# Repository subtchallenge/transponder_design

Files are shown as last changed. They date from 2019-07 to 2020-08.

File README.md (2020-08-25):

# E-Stop Transmitter Design Files

*Version 2 - FEB 2020*

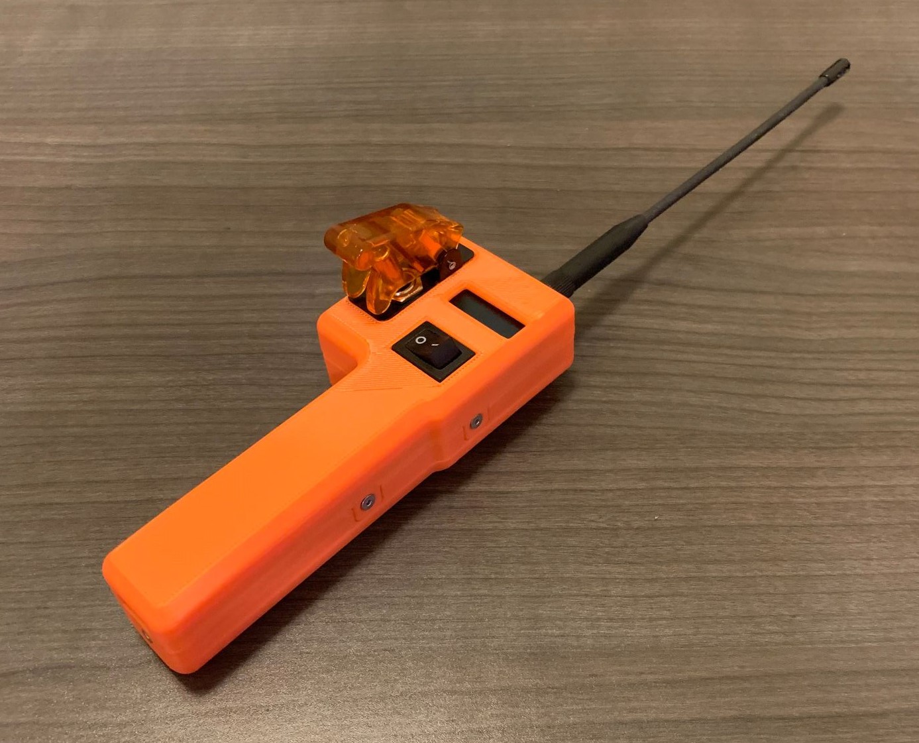
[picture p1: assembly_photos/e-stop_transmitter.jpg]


## Contents:
1. [3D Printing](#1-3d-printing)
2. [XBee Configuration](#2-xbee-configuration)
3. [Assembly](#3-assembly)
4. [Programming](#4-programming)
5. [Operation](#5-operation)

## 1. 3D Printing

The case of the E-Stop transmitter is comprised of two parts: an upper receiver and a lower receiver.  Each receiver houses several components, and the two parts mate together to form the body of the transmitter.

The design files for these parts have been provided in this package:

```
./hardware/lower_receiver.stp
./hardware/upper_receiver.stp
```

These parts are intended to be 3D printed.  The original design allows for printing on a standard desktop FDM 3D printer with a single extruder.  Other printers may be used at your own discretion.

It is recommended that the parts be printed in ABS plastic, however PLA or another form of plastic may be used as well.

For printing on a single-extruder printer without dissolvable filament, both receivers must be printed with the interior (hollow) face mated to the bed of the printer.  Supports must be used.  We recommend using Simplify 3D as a slicer because it has superior support structure generation.

Curling may be an issue for ABS prints due to the low surface area mating the part to the bed.  A raft is recommended for all plastics.  For ABS, a heated build plate and enclosed print volume will be necessary.

After printing, ensure that all dissolvable or supporting material is fully removed, or certain components will not fit (especially the rechargeable battery).

## 2. XBee Configuration

Before assembling your transmitter, you must configure the transmitter's XBee module.  This can be accomplished using Digi's XCTU utility and the XBee configuration file provided in this package.

1. Download and install the XCTU utility from the [Digi website](https://www.digi.com/products/iot-platform/xctu#productsupport-utilities).
2. Connect the XBee to the computer using the USB Adapter Board from your transponder.
3. Click the **Add Radio** button in XCTU to connect to the XBee. Once connected, make sure that your working mode in XCTU is set to _Configuration Mode_.
4. Click the **Profile** button, followed by **Apply Configuration**. This will bring up a dialog to select a configuration profile to upload to your XBee.
5. Select the profile provided in this package at `./xbee_profiles/e-stop_configuration.xpro`. This will start uploading the configuration to your XBee.
6. Set your **Node Identifier (NI)** parameter to match the following format: `my_transmitter_name-my_team_name`. For example, you may use `ES1-DARPA` (where ES1 stands for E-Stop #1, and the team name is DARPA).
    * **NOTE:** Do not use a dash ('-') in any part of the transmitter OR team name. This is a reserved character.
	* **NOTE:** `my_transmitter_name` must be 3 characters or less.
	* **NOTE:** `my_team_name` must be 11 characters or less.
    * **NOTE:** Don't forget to click the **Write** button to save the parameter to your Xbee.
7. You may optionally set a common encryption key for your transmitter and transponder XBees using the **AES Encryption Key (KY)** parameter.

Your e-stop transmitter is now properly configured.

**NOTE:** You may use the same process above to configure your platform transponders.  In step 5, simply load the transponder's configuration instead, which is provided in this package at `./xbee_profiles/transponder_configuration.xpro`.

## 3. Assembly

This section provides all information needed to assemble the E-Stop Transmitter.

**Supporting Files:**

* Electrical Schematic: `./electrical_schematic.jpg`
* Assembly Photos: `./assembly_photos/*`

**Tools Needed:**

* Soldering Iron
* Solder
* Wire Cutter/Stripper
* Exacto Blade
* M2, M2.5, and M3 taps
* 2mm and 2.5mm Hex Drivers
* Hot Glue Gun or Super Glue
* Multimeter
* Crescent Wrench

**Instructions:**

_NOTE: Most steps have supporting images in the assembly_photos directory._

1. Use the metric taps to thread the upper and lower receivers.
    * Use the M2.5 tap on the case mating holes on the sides of the lower receiver.
	* Use the M2 tap for the OLED mounting holes on the lower receiver.
	* Use the M3 tap for the XBee carrier mounting holes on the upper receiver.
2. Insert the battery into the lower receiver, with the wires facing towards the top of the receiver. [(photo)](assembly_photos/step_2.jpg)
3. Attach the _E-Stop Toggle Switch_ to the upper receiver using the following steps:
	* Bend the two bottom pins of the _E-Stop Toggle Switch_ to a 90deg angle. [(photo)](assembly_photos/step_3a.jpg)
    * Adjust the vertical positioning nut on the bore of the switch so that there is just enough thread on the outside of the upper receiver to place the cover and outer nut. [(photo)](assembly_photos/step_3a.jpg)
	* Insert the switch in through the back of the upper receiver, with the side with two pins facing towards the bottom of the upper receiver. [(photo)](assembly_photos/step_3a.jpg)
	* Place the toggle cover (in the open position) on the outside of the upper receiver, and fasten tightly using the second nut. [(photo)](assembly_photos/step_3b.jpg)
4. Attach the _Power Rocker Switch_ to the upper receiver using the following steps:
    * Cut the leads off of the rocker at the bend point. [(photo)](assembly_photos/step_4a.jpg)
	* Insert the rocker switch into the receiver, with the "on" side of the switch on the right side of the receiver. [(photo)](assembly_photos/step_4b.jpg)
5. Configure the _Pro Trinket Lipoly Backpack_ with the following steps:
    * Solder the jumper closed on the back side of the board. [(photo)](assembly_photos/step_5a.jpg)
	* Cut the switch trace on the front side of the board and verify disconnection with a multimeter. [(photo)](assembly_photos/step_5b.jpg)
6. Solder 2x 140mm wires to the switch pins on the _Pro Trinket Lipoly Backpack_. [(photo)](assembly_photos/step_6.jpg)
7. Solder a 3-pin block of male header pins to the USB/G/BAT pins on the top side of the _ItsyBitsy_, and cut excess from the bottom side of the board. [(photo)](assembly_photos/step_7.jpg)
8. Solder the _Pro Trinket Lipoly Backpack_ onto the _ItsyBitsy_, following the schematic. Trim only the USB male pin, leaving the other two pins full length. [(photo)](assembly_photos/step_8.jpg)
9. Solder a 170mm wire and a 10K resistor to Pin 9 on the _ItsyBitsy_. Bend the resistor towards the the 3-pin header block. [(photo)](assembly_photos/step_9.jpg)
10. Solder the 10K resistor from Pin 9 to the G pin of the 3-pin header block, following the schematic. [(photo)](assembly_photos/step_10.jpg)
11. Solder the 15K resistor to the _Pro Trinket Lipoly Backpack_ BAT pin. Bend the resistor towards A3, and insert it through A3 but do not solder yet. [(photo)](assembly_photos/step_11.jpg)
12. Solder a 60mm wire and a 47K resistor into GND on the _ItsyBitsy_, right next to the MISO pin. Bend the resistor towards A3, insert it into A3 along with the 15K resistor from Step 11, and solder both into place. [(photo)](assembly_photos/step_12.jpg)
13. Solder 3x 150mm wires to pins 7, SDA, and SCL on the _ItsyBitsy_. [(photo)](assembly_photos/step_13.jpg)
14. Solder 2x 60mm wires to pins TX and RX on the _ItsyBitsy_. [(photo)](assembly_photos/step_14.jpg)
15. Solder a 140mm wire to the 3V pin on the _ItsyBitsy_. [(photo)](assembly_photos/step_15.jpg)
16. Solder a 150mm and 80mm wire to the VHI pin on the _ItsyBitsy_. [(photo)](assembly_photos/step_16.jpg)
17. Solder a 100mm and 140mm wire to the GND pin next to Pin 8 on the _ItsyBitsy_. [(photo)](assembly_photos/step_17.jpg)
18. Place the _ItsyBitsy_ into the upper receiver, and glue into place at each corner using hot glue or super glue. Be sure not to block the mating channels for the lower receiver. [(photo)](assembly_photos/step_18.jpg)
19. Attach the _OLED Display_ using the following steps:
    * Temporarily place the _OLED Display_ into its position on the upper receiver, with the pin holes towards the top of the receiver.
	* Following the schematic, route the _OLED Display_ wires from the _ItsyBitsy_ up through the receiver to the proper pin positions on the _OLED Display_.
	* Carefully trim any excess wire from the _OLED Display_ wire leads. See [photo](assembly_photos/step_21.jpg) from Step 21 for proper wire routing.
	* Solder the SDA, SCL, Pin 7, VHI, and GND wire leads from the _ItsyBitsy_ to the appropriate pins on the _OLED Display_, following the schematic. [(photo)](assembly_photos/step_19.jpg)
	* Attach the _OLED Display_ to the upper receiver using 4x M2x4mm screws. See [photo](assembly_photos/step_21.jpg) from Step 21 for proper positioning.
20. Solder the _E-Stop Toggle Switch_ wires using the following steps:
    * Route the _E-Stop Toggle Switch_ wires through the upper receiver, aligning the wire leads according to the schematic.  Carefully trim wire leads to appropriate length.  See [photo](assembly_photos/step_21.jpg) from Step 21 for proper wire routing.
	* Solder the 3V, Pin 9, and GND wire leads to the _E-Stop Toggle Switch_ according to the schematic. [(photo)](assembly_photos/step_20.jpg)
21. Solder the _Power Rocker Switch_ wires using the following steps:
	* Route the _Power Rocker Switch_ wires through the upper receiver, aligning the wire leads according to the schematic. Carefully trim wire leads to the appropriate length.  See [(photo)](assembly_photos/step_21.jpg) for proper wire routing.
	* Solder the _Pro Trinket Lipoly Backpack_ switch wire leads to the _Power Rocker Switch_ according to the schematic. [(photo)](assembly_photos/step_21.jpg)
22. Trim the remaining wires from the _ItsyBitsy_ to length, so that they all evenly reach the middle case holes on the sides of the upper receiver. Crimp female contacts onto the wires, and attach a 4-pin rectangular housing according to the schematic. [(photo)](assembly_photos/step_22.jpg)
23. Solder 4x 140mm wires to the GND, 5V, DIN, and DOUT pins on the _XBee Carrier_. [(photo)](assembly_photos/step_23.jpg)
24. Attach the _XBee Carrier_ to the lower receiver using 4x M3x5mm screws. [(photo)](assembly_photos/step_24.jpg)
25. Insert the _XBee Module_ into the _XBee Carrier_, and bend the four wires up over the top of the XBee (positioning two wires on each corner). [(photo)](assembly_photos/step_25.jpg)
26. Trim the _XBee Carrier_ wires to length, so that they all evenly reach the middle case holes on the sides of the lower receiver. Crimp male contacts onto the wires, and attach a 4-pin rectangular housing according to the schematic. [(photo)](assembly_photos/step_26.jpg)
27. Connect the rectangular housings from the upper and lower receivers, being mindful of the polarity and following the schematic.
28. Connect the battery leads to the _Pro Trinket Lipoly Backpack_, being mindful of the polarity.
29. Attach the upper receiver casing to the lower receiver casing using 6x M2.5x5mm flathead screws. When attaching, ensure that all wires are positioned safely inside of the receivers, and not straddling the mating edges of the receivers. Depending on the quality of the print, you may need to forcefully press the two receivers together to align the holes for the flathead screws. Be careful not to strip the threads in the receiver plastic. [(photo)](assembly_photos/e-stop_transmitter.jpg)

## 4. Programming

This package includes all necessary Arduino code for the E-Stop transmitter under the `./arduino_code/` directory.

**Installation**

1. Copy all directories from this package's `./arduino_code/libraries/` directory into your local `Arduino/libraries/` directory.
2. Copy this package's `./arduino_code/estop_transmitter` directory to your local `Arduino/` directory.

**Uploading**

1. Attach a USB cable to your computer and through the _ItsyBitsy_ USB port that is exposed at the bottom of the transmitter handle.
2. Open the Arduino IDE and configure it for programming the _ItsyBitsy 32u4 3V_ microcontroller.  Follow the [instructions](https://learn.adafruit.com/introducting-itsy-bitsy-32u4/arduino-ide-setup) provided by Adafruit for proper configuration. **NOTE:** Ensure that you configure the IDE for the **3V** version of the _ItsyBitsy_ and **NOT** the 5V version.
3. Open the `estop_transmitter` sketch in the Arduino IDE and upload it to the _ItsyBitsy_.

## 5. Operation

**Charging:**

The USB Micro B port located at the bottom of the transmitter handle is used to charge the internal battery.  Connect this to a 5V, 2A USB power supply (phone chargers are fine).  You will see a red light turn on inside of the transmitter, which will be visible through the 3D printed plastic if you used orange ABS or PLA.  This light indicates that it is charging.  The charger circuit will automatically turn off when the battery is fully charged.

**Usage:**

Use the _Power Rocker Switch_ to turn on the transmitter.  A "Loading..." screen will display while the transmitter powers up.  **NOTE:** Always ensure that the _E-Stop Toggle Switch_ is in the **OFF** position before turning on the transmitter.

Once the transmitter is fully powered on and ready to operate, the display will show the following:

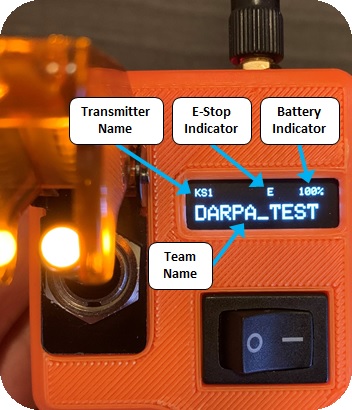
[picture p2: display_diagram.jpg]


When you want to trigger an emergency stop, simply open the toggle switch guard and flip the switch to the ON position.  You will see the light on the toggle switch turn on.  This will immediately start broadcasting emergency stop messages, and will continue to do so until you switch the toggle switch back into the OFF position.  The display will show an "E" at the top center whenever it is broadcasting emergency stop messages.

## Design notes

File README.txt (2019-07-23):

EMERGECNY STOP TRANSMITTER README

VERSION 1 - JUNE 21 2019

CONTENTS:
  1. 3D Printing Case
  2. Assembly
  3. Programming
  4. Configuring
  5. Operation

1. 3D Printing Case

The case of the E-Stop transmitter is comprised of two parts: an upper receiver and a lower receiver.  Each receiver houses several components, and the two parts mate together to form the body of the transmitter.

The design files for these parts have been provided in this package:
  - Lower Receiver.stp
  - Upper Receiver.stp
  
These parts are intended to be 3D printed.  The original design allows for printing on a standard desktop FDM 3D printer with a single extruder.  Other printers may be used at your own discretion.

It is recommended that the parts be printed in ABS plastic, however PLA or another form of plastic may be used as well.

For printing on a single-extruder printer without dissolvable filament, both receivers must be printed with the interior (hollow) face mated to the bed of the printer.  Supports must be used.  We recommend using Simplify 3D as a slicer because it has superior support structure generation.

Curling may be an issue for ABS prints due to the low surface area mating the part to the bed.  A raft is recommended for all plastics.  For ABS, a heated build plate and enclosed print volume will be necessary.

After printing, ensure that all dissolvable or supporting material is fully removed, or certain components will not fit (especially the rechargeable battery).

2.  Assembly

Tools Needed: Soldering Iron + Solder, Wire Cutter/Stripper, 2mm and 2.5mm Hex Drivers, Crescent Wrench

The schematic has been provided in this package:
  - Schematic.jpg

The assembly for the transmitter is relatively complicated due to the dense population of components inside of the upper and lower receivers.  It is recommended that you first place the components into the receivers, follow the schematic, and cut wires to the appropriate lengths.  Keep in mind spacing required for putting the two receiver halves together.

NOTE: Before soldering components, if you only have one XBee USB Adapter board, perform the configuration step for the XBee first (Section 4 of this README).  This allows you to configure the XBee using the USB adapter board before soldering and integrating it into the lower receiver.

Once the wire lengths are measured and cut, remove the components and begin soldering wires and resistors into place using the included schematic.  Be careful that nearby resistors leads are not touching.  It is VERY IMPORTANT that you follow the schematic exactly.  If done incorrectly, you may damage one or more of the components.  You may also cause the Lithium Ion rechargeable battery to catch fire.

The toggle switch must have its two bottom pins/pads bent outwards at a 90deg angle in order to fit into the lower receiver.

The RC rectangular header is needed to physically separate the two receiver halves since they are connected by a shared wiring harness.  The best location for this connector is directly above the XBee radio.  Ensure that the connector attached to the XBee and the Battery uses FEMALE PINS.

Do not attach the locking spacer and nut onto the XBee RP-SMA until after the upper and lower receivers are attached together.  Once the locking spacer and nut are attached, you may attach the duck antenna.  You may use a crescent wrench or other similar wrench for tightening the nut on the XBee RP-SMA connector.

When attaching the two receivers with the flathead screws, you have the option of either tapping the holes with an M2.5 metric tap, or screwing directly into the hole without tapping.  Tapping the hole ahead of time will make assembly easier, but increases the risk of stripping the plastic.  The screws can be self-tapped with a little more torque, but again be careful to not strip the plastic.  You may have to compress the two receivers together to align all of the holes.

3.  Programming

This package includes and Arduino sketch in the form of an INO file.  This file is ready to be uploaded to the trinket via USB.  Adafruit has provided a step-by-step guide for configuring a PC and the Arduino IDE to upload sketches to the Trinket.  The link can be found below.  Please follow these directions VERY CAREFULLY.  You must ensure that you choose the 3V version of the board, not the 5V version.  You must also make sure to choose the USBtinyISP as the programmer.  Failure to take these vital steps may brick the Trinket.
https://learn.adafruit.com/introducing-pro-trinket/downloads

Once your PC and Arduino IDE is configured to upload sketches to the Trinket, you may upload the INO file/sketch provided in this package.

4.  Configuring

Next, you must configure the XBee in the transmitter.  This can be accomplished using Digi's XCTU utility and the XBee configuration file provided in this package.  Plug your XBee into a PC running XCTU through the USB XBee Adapter baord.  Next, use the XCTU configuration uploading tool to upload the configuration to the XBee that will be installed in the transmitter.  Once you upload the configuration to the XBee through XCTU, ensure that the encryption key is set to match your team's supplied private encryption key.

5.  Operation

Charging: The USB Micro B port located at the bottom of the transmitter handle is used to charge the internal battery.  Connect this to a 5V, 2A USB power supply (phone chargers are fine).  You will see a yellow/orange light turn on inside of the transmitter, which will be visible through the 3D printed plastic if you used orange ABS or PLA.  This light indicates that it is charging.  The charger circuit will automatically turn off when the battery is fully charged.

Usage: When you want to trigger an emergency stop, simply open the toggle switch guard and flip the switch to the ON position.  You will see the light on the toggle switch turn on.  This will immediately start broadcasting emergency stop messages, and will continue to do so until you switch the toggle switch back into the OFF position.

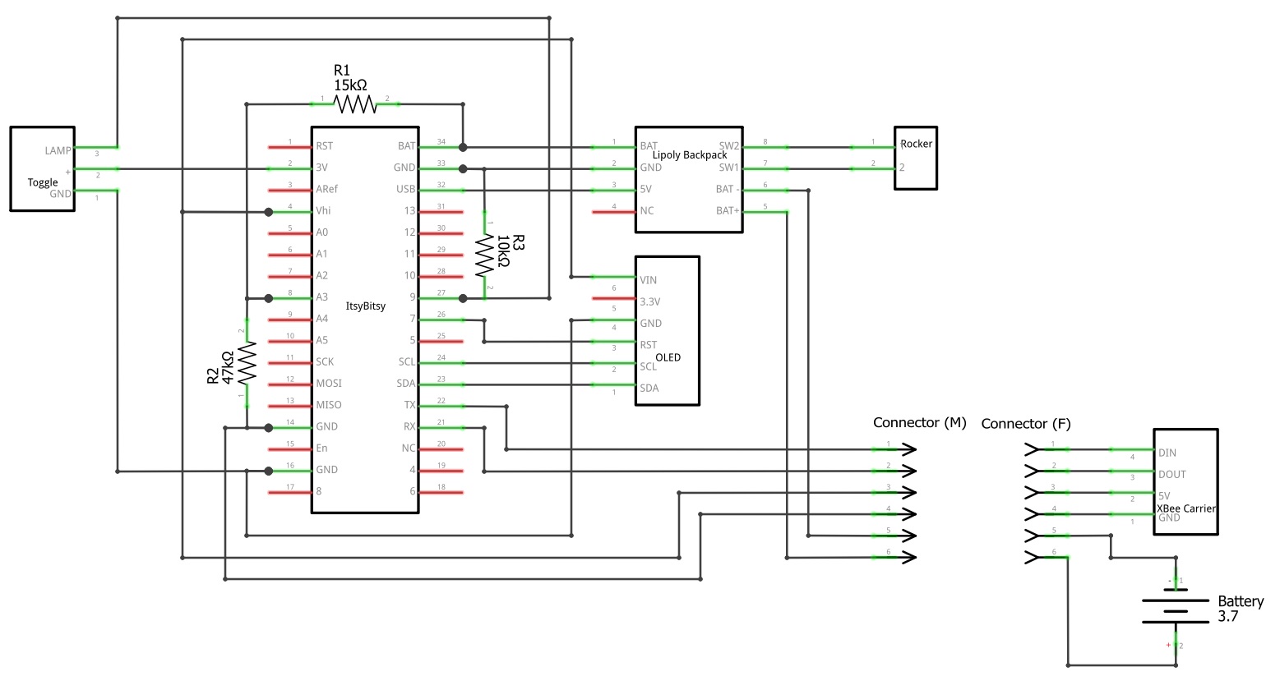
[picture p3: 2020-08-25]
electrical_schematic.jpg

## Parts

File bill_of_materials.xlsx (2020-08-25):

Description | Group | Model | Vendor | Price | Qty | Total | Link
Microcontroller | Components | ItsyBitsy 32u4 3.3V | Adafruit | $9.95 | 1 | $9.95 | https://www.adafruit.com/product/3675
Battery Charger | Components | LiPoly Backpack | Adafruit | $4.95 | 1 | $4.95 | https://www.adafruit.com/product/2124
OLED Display | Components | 128x32 Monochrome I2C Display | Adafruit | $17.50 | 1 | $17.50 | https://www.adafruit.com/product/4440
Toggle Switch | Components | Illuminated Toggle Switch - Yellow | Adafruit | $2.95 | 1 | $2.95 | https://www.adafruit.com/product/3219
Li-Ion Battery | Components | Lithium Ion Cylindrical Battery 3.7V 2200mAh | Adafruit | $9.95 | 1 | $9.95 | https://www.adafruit.com/product/1781
Xbee Carrier | Components | Xbee Explorer Regulated | Sparkfun | $10.95 | 1 | $10.95 | https://www.sparkfun.com/products/11373
Rocker Switch | Components | Rocker Switch - SPST | Sparkfun | $0.95 | 1 | $0.95 | https://www.sparkfun.com/products/8837
XBee | Components | Xbee Pro 900HP | Mouser | $42.90 | 1 | $42.90 | https://www.mouser.com/ProductDetail/Digi-International/XBP9B-DMST-002?qs=%2Fsr0sUXBX%2Foiu%252b5b6BKNJQ%3D%3D
XBee Antenna | Components | 900MHz Duck Antenna | Mouser | $20.00 | 1 | $20.00 | https://www.mouser.com/ProductDetail/Digi-International/A09-HSM-7?qs=zorda86t5M%2F8nPmqFG0UfQ%3D%3D
XBee Carrier Screws | Fasteners | M3x5 Socket Head Screw (100 pack) | McMaster | $4.97 | 1 | $4.97 | https://www.mcmaster.com/91292A110/
OLED Display Screws | Fasteners | M2x4 Socket Head Screw (100 pack) | McMaster | $13.06 | 1 | $13.06 | https://www.mcmaster.com/91292A004/
Receiver Case Screws | Fasteners | M2.5x5 Flathead Screw (25 pack) | McMaster | $3.84 | 1 | $3.84 | https://www.mcmaster.com/93395A173/
Resistor 10K | Electrical | Resistor 10K Ohm 1/4W (100 Pack) | Amazon | $7 | 1 | $7.00 | https://www.amazon.com/Projects-100EP51410K0-10k-Resistors-Pack/dp/B0185FGYQA
Resistor 15K | Electrical | Resistor 15K Ohm 1/4W (25 Pack) | Amazon | $4 | 1 | $4.00 | https://www.amazon.com/Projects-100EP51415K0-15k-Resistors-Pack/dp/B01F06T4RS
Resistor 47K | Electrical | Resistor 47K Ohm 1/4W (100 Pack) | Amazon | $7.00 | 1 | $7.00 | https://www.amazon.com/Projects-25EP51447K0-47k-Resistors-Pack/dp/B0185FGZ5K
Connector 4-pin | Electrical | Connector Housing 1x4 Pin (10 Pack) | Pololu | $0.59 | 1 | $0.59 | https://www.pololu.com/product/1903
Contacts (M) | Electrical | Crimp Pins (M) (100 Pack) | Pololu | $8.00 | 1 | $8.00 | https://www.pololu.com/product/1931
Contacts (F) | Electrical | Crimp Pins (F) (100 Pack) | Pololu | $6.00 | 1 | $6.00 | https://www.pololu.com/product/1930
3D Printer Filament | 3D Printing | Hatchbox ABS Orange - 1.75mm, 1kg Spool | Amazon | $22.00 | 1 | $22.00 | https://www.amazon.com/HATCHBOX-3D-Filament-Dimensional-Accuracy/dp/B00J0H4EVU

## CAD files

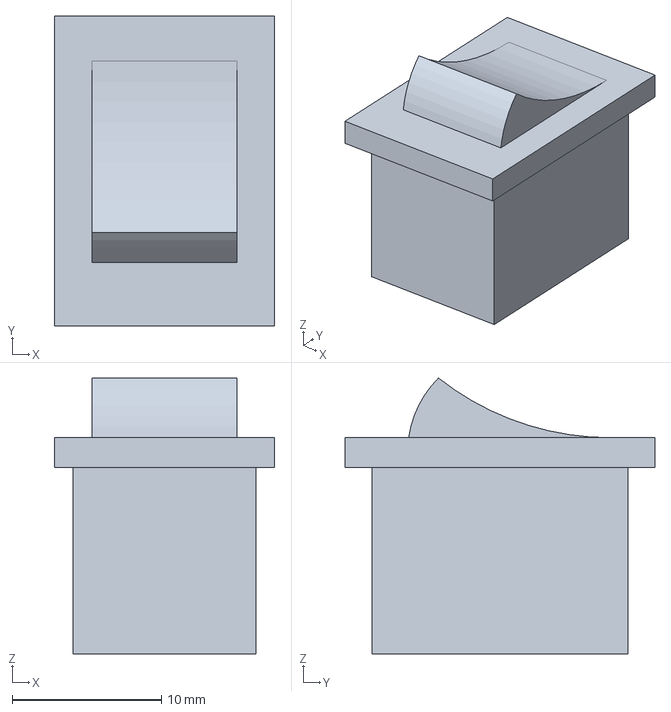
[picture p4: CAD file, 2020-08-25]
hardware/components/power_switch.stp
14.8 x 20.8 x 18.5 mm

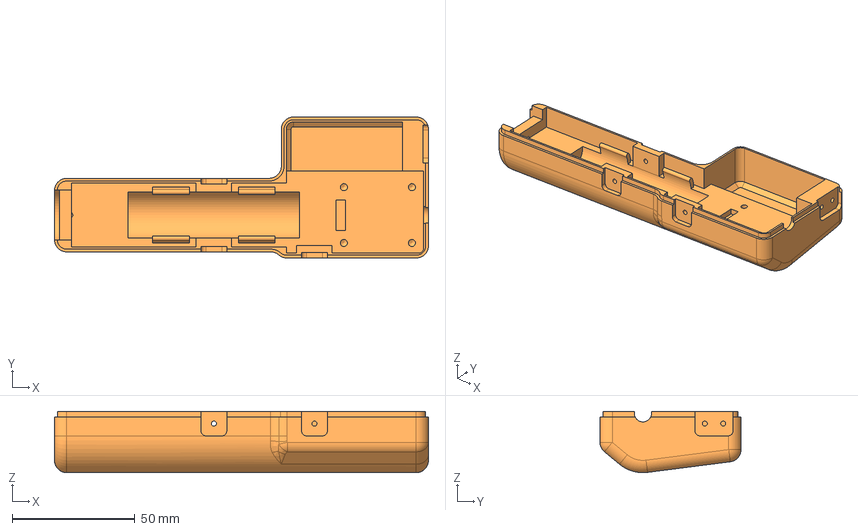
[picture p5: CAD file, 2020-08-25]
hardware/lower_receiver.stp
152.5 x 57.5 x 25.0 mm

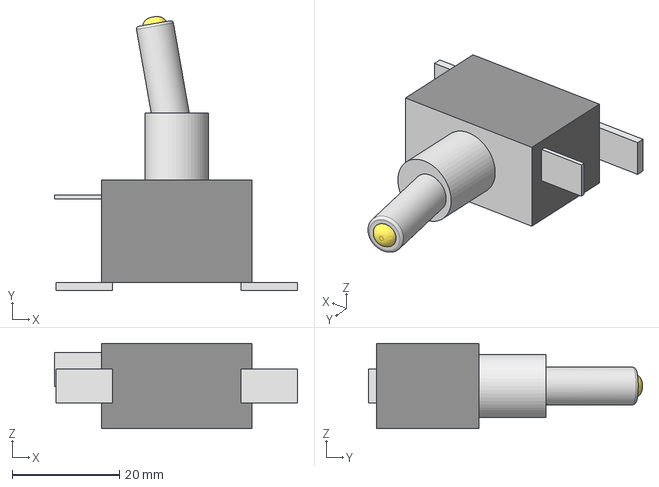
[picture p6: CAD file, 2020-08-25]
hardware/components/stop_switch.stp
45.3 x 51.1 x 15.9 mm

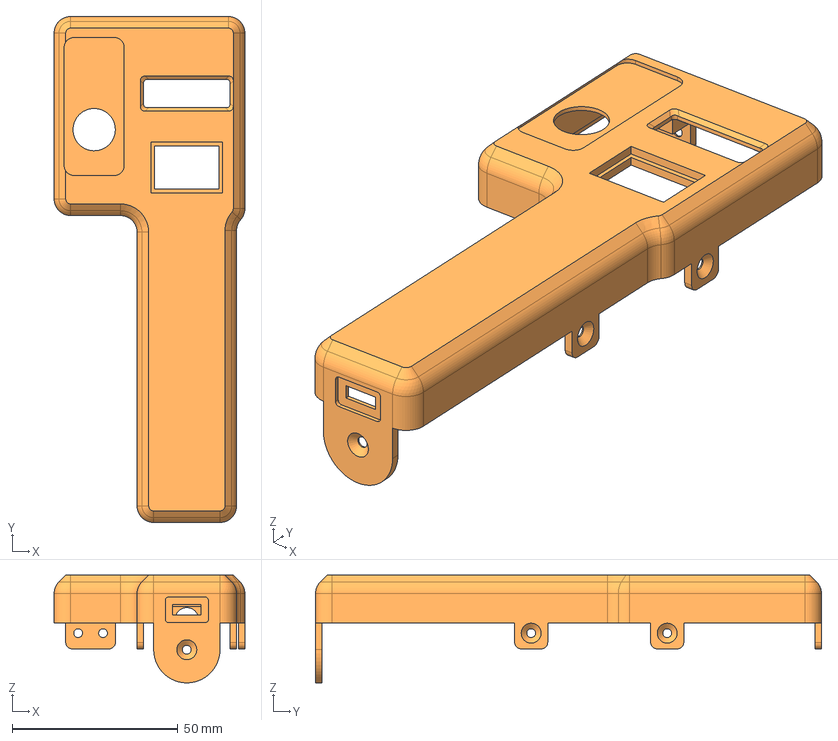
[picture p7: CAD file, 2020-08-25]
hardware/upper_receiver.stp
57.5 x 152.5 x 32.5 mm

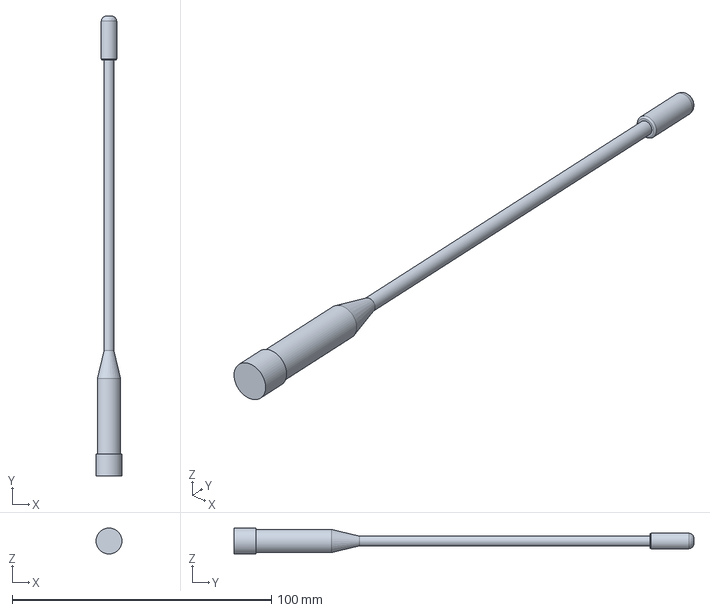
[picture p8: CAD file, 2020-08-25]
hardware/components/antenna.stp
10.0 x 177.3 x 10.0 mm

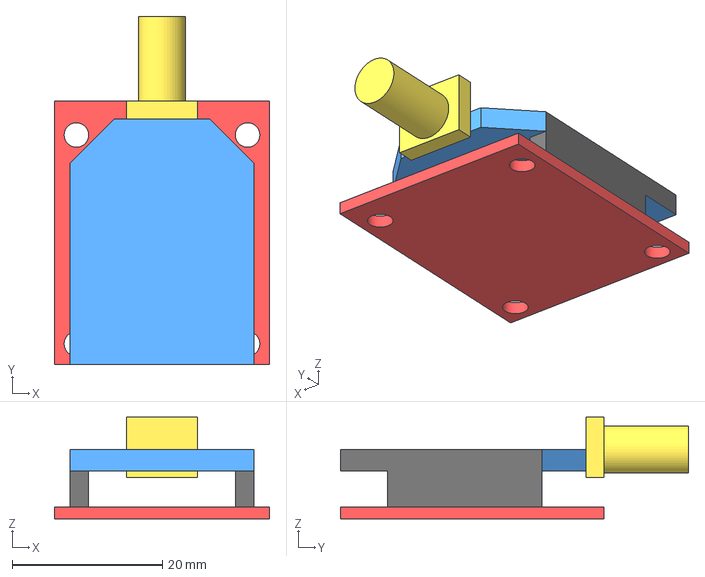
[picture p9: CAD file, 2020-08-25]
hardware/components/xbee_carrier.stp
28.6 x 46.2 x 13.5 mm

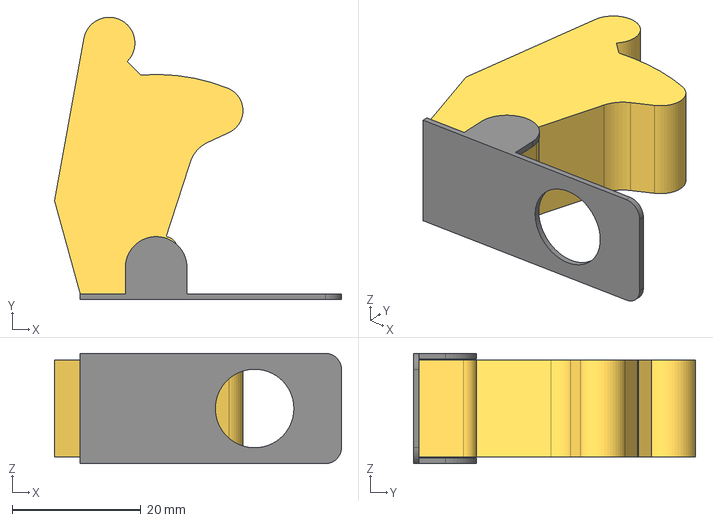
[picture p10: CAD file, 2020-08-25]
hardware/components/stop_switch_guard.stp
44.6 x 43.9 x 17.2 mm

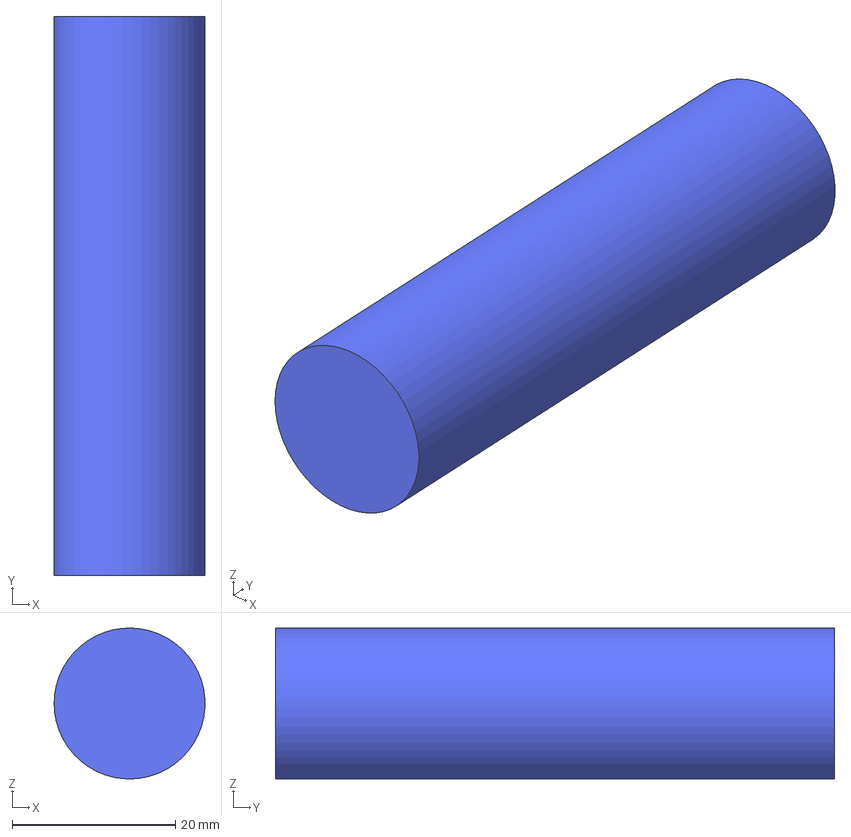
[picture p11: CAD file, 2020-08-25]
hardware/components/battery.stp
18.5 x 68.5 x 18.5 mm

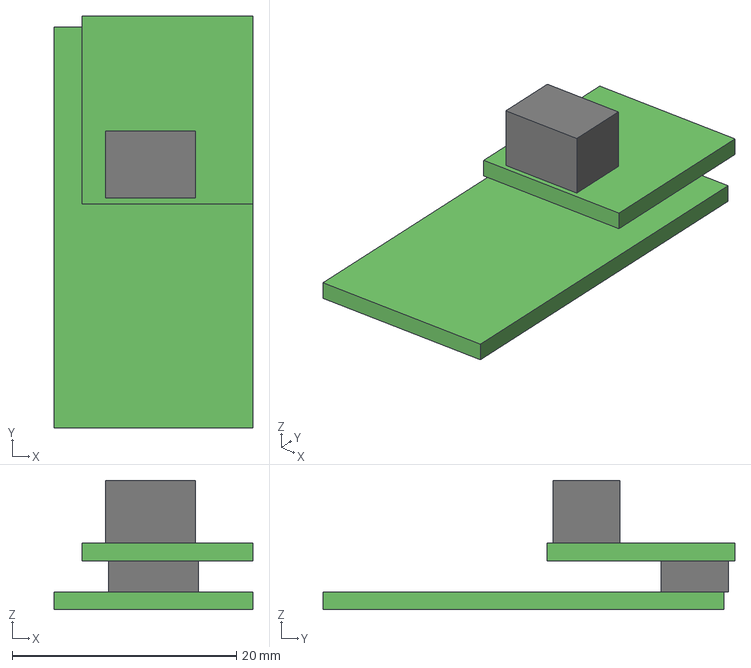
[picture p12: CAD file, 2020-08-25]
hardware/components/itsy_bitsy.stp
17.8 x 36.8 x 11.6 mm

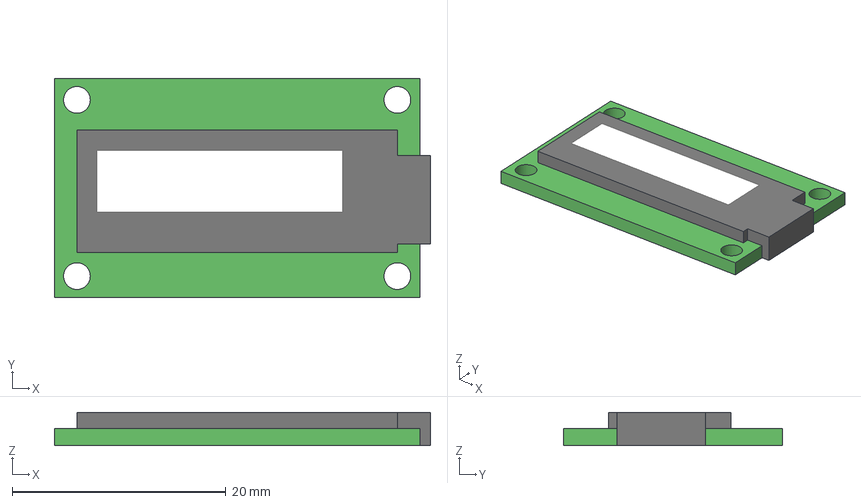
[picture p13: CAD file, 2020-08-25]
hardware/components/oled_display.stp
35.2 x 20.5 x 3.10 mm

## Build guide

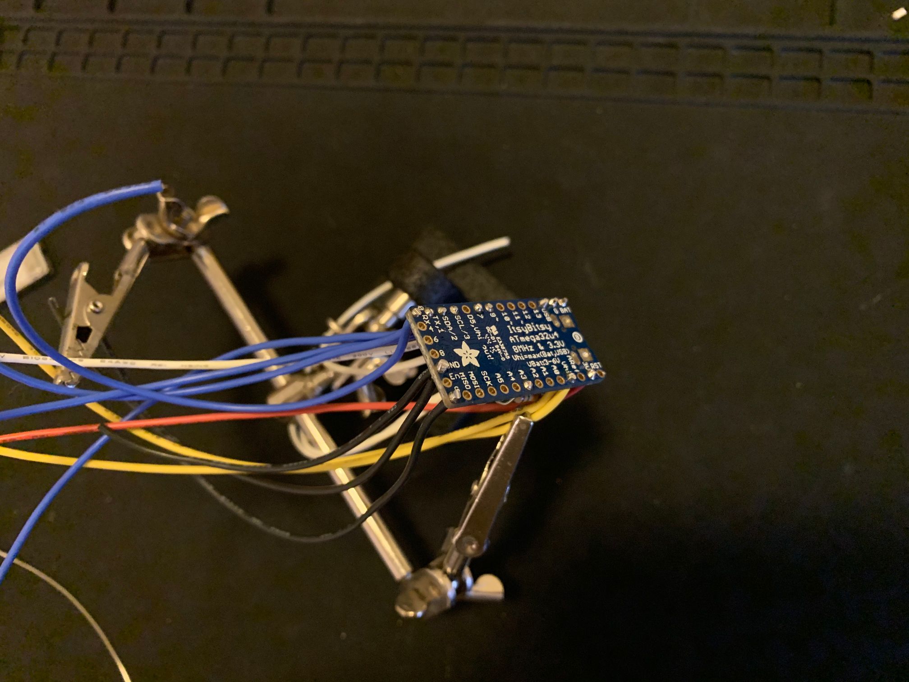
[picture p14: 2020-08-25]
assembly_photos/step_17.jpg

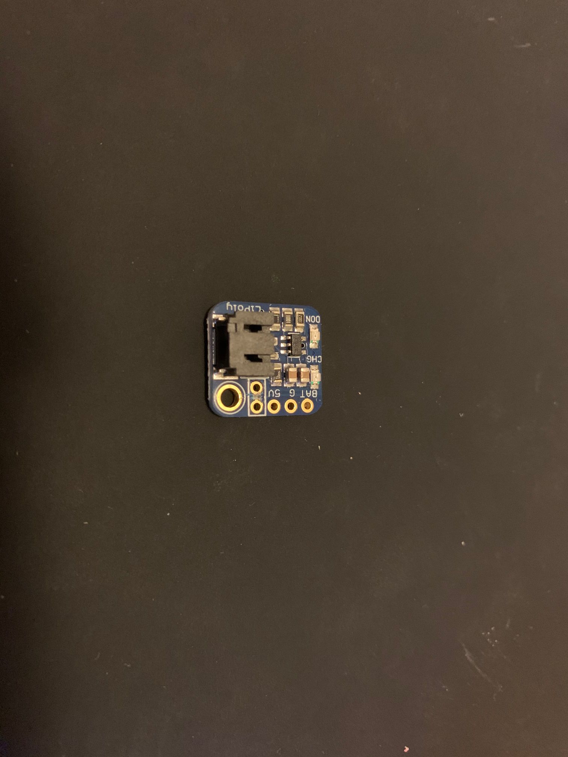
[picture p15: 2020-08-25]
assembly_photos/step_5b.jpg

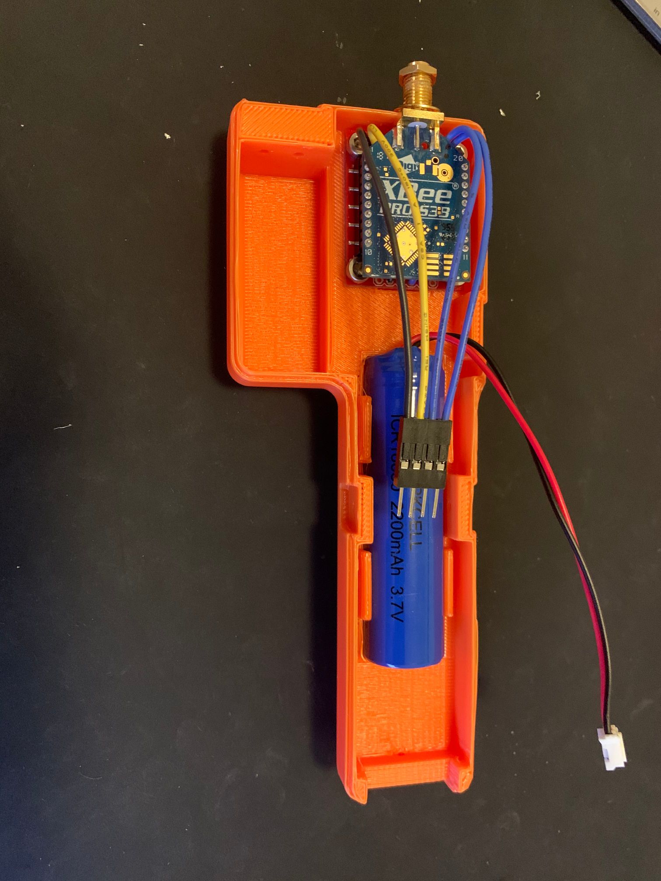
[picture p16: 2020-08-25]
assembly_photos/step_26.jpg

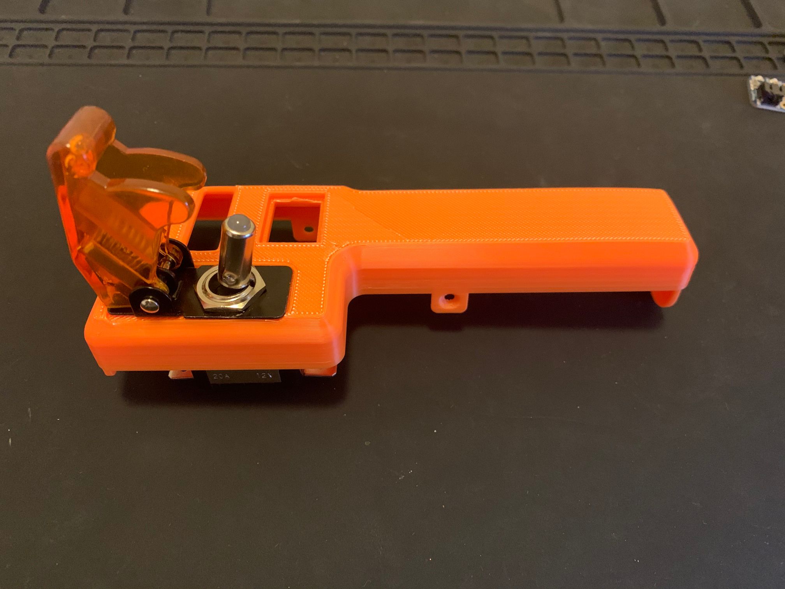
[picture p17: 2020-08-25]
assembly_photos/step_3b.jpg

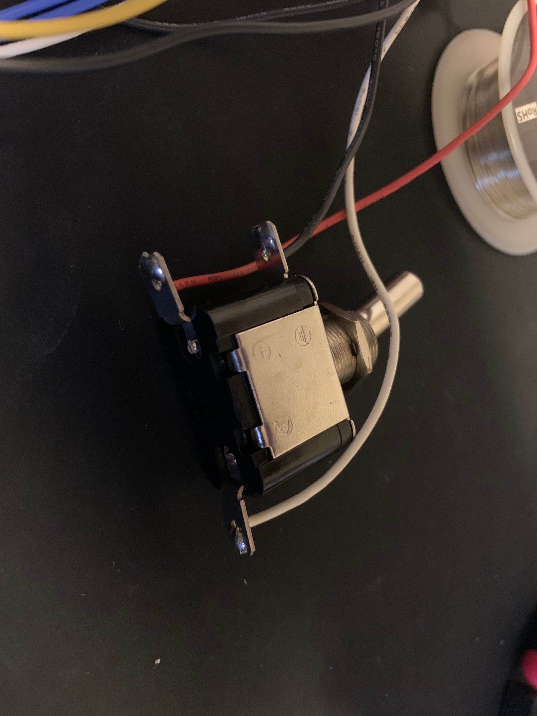
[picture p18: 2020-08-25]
assembly_photos/step_20.jpg

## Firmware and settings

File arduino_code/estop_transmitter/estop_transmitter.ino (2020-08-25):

#include "battery_monitor.h"
#include "xbee.h"
#include "estop_controller.h"
#include "serial_manager.h"
#include "oled_display.h"

estop::battery_monitor* battery_monitor;
estop::xbee* xbee;
estop::estop_controller* estop_controller;
estop::serial_manager* serial_manager;
estop::oled_display* oled;

void setup()
{
  // Open serial ports and set timeouts.
  Serial.begin(9600);
  Serial.setTimeout(50);
  Serial1.begin(9600);
  Serial1.setTimeout(50);

  // Initialize components.  
  battery_monitor = new estop::battery_monitor();
  xbee = new estop::xbee();
  estop_controller = new estop::estop_controller(battery_monitor, xbee);
  serial_manager = new estop::serial_manager(xbee);
  oled = new estop::oled_display(battery_monitor, xbee, estop_controller, serial_manager);

  // Display loading splash, and wait for XBee to come online.
  oled->splash();
  delay(500);
  // Probe XBee for device/team names and display.
  oled->update_names();
}

void loop()
{
  // Spin components.
  estop_controller->spin_once();
  serial_manager->spin_once();
  oled->spin_once();
  
  // Sleep for 25ms before looping.
  delay(25);
}

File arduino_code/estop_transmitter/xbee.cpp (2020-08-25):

#include "xbee.h"

using namespace estop;

// PUBLIC METHODS
bool xbee::set_node_identifier(const char* identifier, uint16_t length)
{
  // Create a data packet to set NI.
  uint16_t data_length = 4 + length;
  uint8_t* data = new uint8_t[data_length];

  // Write fields.
  data[0] = 0x08;               // Frame Type: 0x08 AT Command
  data[1] = 0x01;               // Frame ID: 1
  data[2] = 0x4E;               // AT Command: NI = 0x4E49
  data[3] = 0x49;               // AT Command: NI = 0x4E49
  // Write identifier string.
  for(uint16_t i = 0; i < length; i++)
  {
    data[4+i] = identifier[i];
  }

  // Send the packet.
  xbee::send_message(data, data_length);
  
  // Get ACK from XBee.
  return xbee::at_ack('N', 'I');
}

bool xbee::get_node_identifier(char*& identifier, uint16_t& length)
{
  // Create data packet to query NI.
  uint16_t data_length = 4;
  uint8_t* data = new uint8_t[data_length];

  // Write fields.
  data[0] = 0x08;               // Frame Type: 0x08 AT Command
  data[1] = 0x01;               // Frame ID: 1
  data[2] = 0x4E;               // AT Command: NI = 0x4E49
  data[3] = 0x49;               // AT Command: NI = 0x4E49

  // Send the query packet.
  xbee::send_message(data, data_length);

  // Get response from XBee.
  uint8_t* response = NULL;
  uint16_t response_length;
  if(xbee::read_response(0x88, response, response_length))
  {
    // Calculate string length.
    length = response_length - 9;
    // Copy the name bytes into the output buffer.
    identifier = new char[length];
    for(uint16_t i = 0; i < length; i++)
    {
      identifier[i] = response[8+i];
    }

    // Clean up response.
    delete [] response;
    
    return true;
  }
  else
  {
    // Did not get a response from the XBee.
    return false;
  }
}

bool xbee::set_team_name(const char* team_name, uint16_t length)
{
  // XBee node identifier will always be in the following format: device_name-team_name.
  // First, get the current node identifier to extract the device name.
  char* current_node_identifier = NULL;
  uint16_t current_node_identifier_length = 0;
  if(!xbee::get_node_identifier(current_node_identifier, current_node_identifier_length))
  {
    delete [] current_node_identifier;
    return false;
  }

  // Extract the device name.
  char* device_name = NULL;
  uint16_t device_name_length = 0;
  xbee::extract_device_name(current_node_identifier, current_node_identifier_length, device_name, device_name_length);

  // Create a new string for the new node identifier.
  // Calculate length of new node identifier
  uint16_t new_node_identifier_length = device_name_length + 1 + length;
  char* new_node_identifier = new char[new_node_identifier_length];
  
  // Populate the string.
  uint16_t i = 0;
  for(uint16_t j = 0; j < device_name_length; j++)
  {
    new_node_identifier[i++] = device_name[j];
  }
  new_node_identifier[i++] = '-';
  for(uint16_t j = 0; j < length; j++)
  {
    new_node_identifier[i++] = team_name[j];
  }

  // Set the new node identifier.
  bool success = xbee::set_node_identifier(new_node_identifier, new_node_identifier_length);

  // Delete strings.
  delete [] new_node_identifier;
  delete [] device_name;
  delete [] current_node_identifier;

  return success;
}

bool xbee::set_encryption_key(const char* encryption_key, uint16_t length)
{
  // Create a data packet to set NI.
  uint16_t data_length = 4 + length;
  uint8_t* data = new uint8_t[data_length];

  // Write fields.
  data[0] = 0x08;               // Frame Type: 0x08 AT Command
  data[1] = 0x01;               // Frame ID: 1
  data[2] = 0x4B;               // AT Command: KY = 0x4B59
  data[3] = 0x59;               // AT Command: KY = 0x4B59
  // Write identifier string.
  for(uint16_t i = 0; i < length; i++)
  {
    data[4+i] = encryption_key[i];
  }

  // Send the packet.
  xbee::send_message(data, data_length);
  
  // Get command ACK from XBee.
  return xbee::at_ack('K', 'Y');
}

bool xbee::save_configuration()
{
  // Create a data packet to send WR command.
  uint16_t data_length = 4;
  uint8_t* data = new uint8_t[data_length];

  // Write fields.
  data[0] = 0x08;               // Frame Type: 0x08 AT Command
  data[1] = 0x01;               // Frame ID: 1
  data[2] = 0x57;               // AT Command: WR = 0x5752
  data[3] = 0x52;               // AT Command: WR = 0x5752

  // Temporarily increase the XBee serial timeout, since writes can take time.
  uint32_t original_timeout = Serial1.getTimeout();
  Serial1.setTimeout(2000);

  // Send the packet.
  xbee::send_message(data, data_length);
  
  // Get ACK from XBee.
  bool ack = xbee::at_ack('W', 'R');

  // Restore original timeout.
  Serial1.setTimeout(original_timeout);

  // Return ack.
  return ack;
}

void xbee::broadcast_estop()
{
  // Create a data packet.
  uint8_t* data = new uint8_t[16];

  // Write fields.
  data[0] = 0x17;               // Frame Type: 0x17 Remote AT Command
  data[1] = 0x01;               // Frame ID: 1
  data[2] = 0x00;               // 64b Address = 0x00 00 00 00 00 00 FF FF (Broadcast)
  data[3] = 0x00;               // 64b Address = 0x00 00 00 00 00 00 FF FF
  data[4] = 0x00;               // 64b Address = 0x00 00 00 00 00 00 FF FF
  data[5] = 0x00;               // 64b Address = 0x00 00 00 00 00 00 FF FF
  data[6] = 0x00;               // 64b Address = 0x00 00 00 00 00 00 FF FF
  data[7] = 0x00;               // 64b Address = 0x00 00 00 00 00 00 FF FF
  data[8] = 0xFF;               // 64b Address = 0x00 00 00 00 00 00 FF FF
  data[9] = 0xFF;               // 64b Address = 0x00 00 00 00 00 00 FF FF
  data[10] = 0xFF;              // 16b Address = 0xFF FE (Reserved)
  data[11] = 0xFE;              // 16b Address = 0xFF FE (Reserved)
  data[12] = 0x03;              // Remote CMD Options = 0b11 (Disable ACK, Apply Changes)
  data[13] = 0x44;              // AT Command: D1 = 0x4431
  data[14] = 0x31;              // AT Command: D1 = 0x4431
  data[15] = 0x05;              // Param Value: Digital Output (High) = 0x05

  // Send the data packet.
  xbee::send_message(data, 16);

  // Read out respnses just to keep RX buffer clear.
  // TODO: These responses can be used to figure out how many robots are responding.
  uint8_t* response = NULL;
  uint16_t response_length;
  // Read until timeout.
  while(xbee::read_response(0x97, response, response_length))
  {
    // Clean up any read response.
    delete [] response;
  }
}
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

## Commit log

2019-07-23 Initial transfer of design files into repository.
    [Antenna.stp, BOM.xlsx, Battery.stp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]
2019-08-02 Added in XCTU files, including firmware, profile, and e-stop frame
2020-07-13 removed v1 hardware design files
    [Antenna.stp, Battery.stp, Lower Reciever.stp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]
2020-07-13 added v2 hardware design files
    [antenna.stp, battery.stp, itsy_bitsy.stp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]
2020-07-13 updated bill of materials
    [BOM.xlsx, bill_of_materials.xlsx]
2020-07-13 updated electrical schematic
2020-07-13 updated arduino code and added dependencies
2020-07-13 added fasteners to bill of materials
    [bill_of_materials.xlsx]
2020-07-13 removed leftover readme from arduino_code directory
2020-07-13 added photos for assembly and operation instructions
